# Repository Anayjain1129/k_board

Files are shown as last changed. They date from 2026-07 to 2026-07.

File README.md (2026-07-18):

# K-Board



# Features:

- Rotary Encoder for volume control
- Raspberry Pi Pico
- Customised layout
- QMK firmware
- Awesome Case

# Schematics


# PCB


# Case






# 3d View of all parts together



# BOM
| Name | Quantity | Cost | Link |
|---|---|---|---|
| TTC Silent Red V3 | 84 | $45.11 | [Buy](https://stackskb.com/store/ttc-silent-red-v3-switch/) |
| Durock Smokey Screw-In Stabilizers V2 (4+1 w/ 6.25u spacebar) | 1 | $17.01 | [Buy](https://stackskb.com/store/durock-smokey-screw-in-stabilizers-v2/) |
| EC11 Rotary Encoder with Switch | 1 | $0.00 | Self-sourced |
| Mount Fuji Premium Moa Profile PBT Keycap | 1 | $28.78 | [Buy](https://curiositycaps.in/products/fugaju-premium-moa-profile-pbt-keycap?_pos=21&_sid=c0043ab41&_ss=r) |
| Diode 1N4148 Through-Hole | 100 | $1.06 | [Buy](https://www.amazon.in/dp/B084ZP5BJ3) |
| PCB - (Black Color) | 5 | $40.00 | [Buy](https://jlcpcb.com/) |
| Raspberry Pi Pico | 1 | $6.40 | [Buy](https://www.amazon.in/Raspberry-Pi-Headers-Soldered-Micro/dp/B08WPNM7JB) |
| Heatset and Screws | 1 | $0.00 | Self-sourced |
| Case (top, mid, bot) | 1 | $0.00 | Self-sourced |
| **Total** | | **$138.36** | |

The price may fluctuate due to dollar market trend

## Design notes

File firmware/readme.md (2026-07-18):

# k_board

k_board

*A short description of the keyboard/project*

* Keyboard Maintainer: [Anayjain1129](https://github.com/Anayjain1129)
* Hardware Supported: *The PCBs, controllers supported*
* Hardware Availability: *Links to where you can find this hardware*

Make example for this keyboard (after setting up your build environment):

    make k_board:default

Flashing example for this keyboard:

    make k_board:default:flash

See the [build environment setup](https://docs.qmk.fm/#/getting_started_build_tools) and the [make instructions](https://docs.qmk.fm/#/getting_started_make_guide) for more information. Brand new to QMK? Start with our [Complete Newbs Guide](https://docs.qmk.fm/#/newbs).

## Bootloader

Enter the bootloader in 3 ways:

* **Bootmagic reset**: Hold down the key at (0,0) in the matrix (usually the top left key or Escape) and plug in the keyboard
* **Physical reset button**: Briefly press the button on the back of the PCB - some may have pads you must short instead
* **Keycode in layout**: Press the key mapped to `QK_BOOT` if it is available

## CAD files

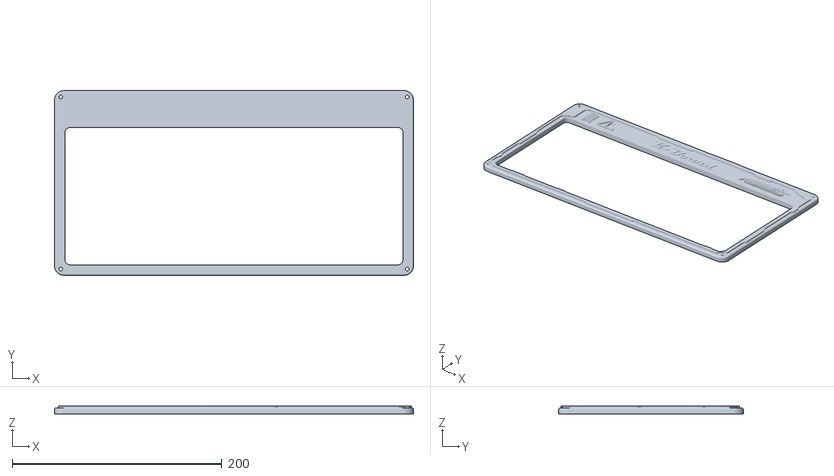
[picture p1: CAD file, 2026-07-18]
cad/top.stl
342.7 x 176.3 x 8.00

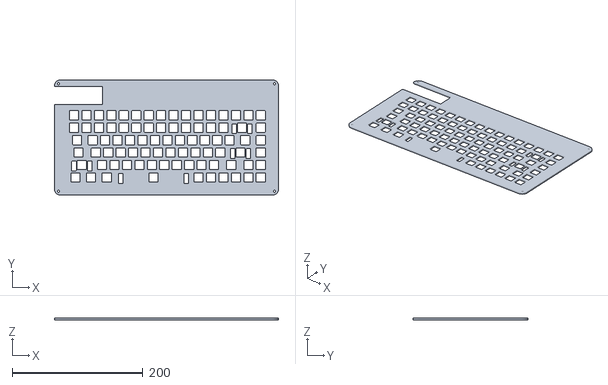
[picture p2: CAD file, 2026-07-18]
production/cad/middle.stl
342.7 x 176.3 x 2.50

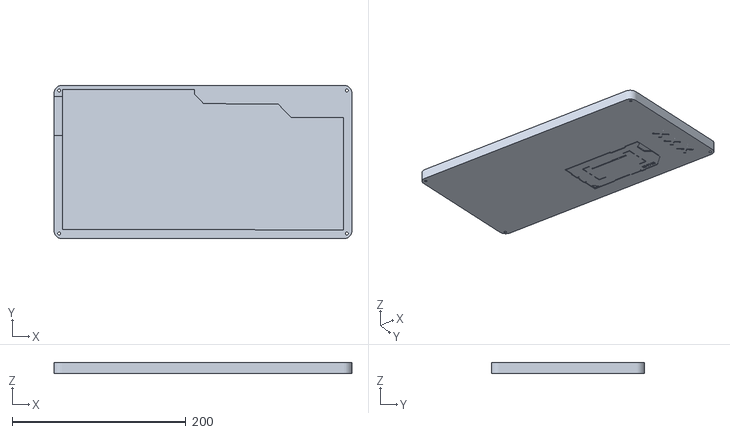
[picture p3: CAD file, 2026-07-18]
cad/bottom.stl
342.7 x 176.3 x 13.0

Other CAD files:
cad/assembly.f3z
cad/bottom.f3d
cad/middle.f3d
cad/top.f3d

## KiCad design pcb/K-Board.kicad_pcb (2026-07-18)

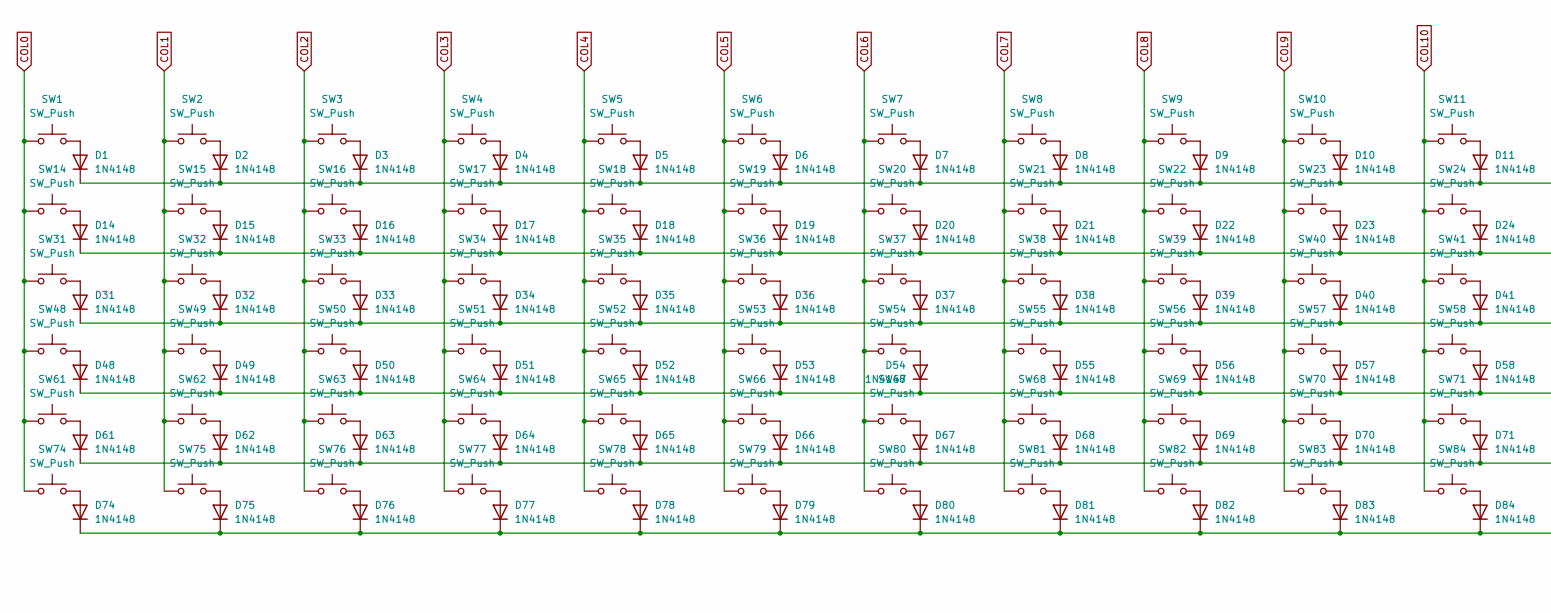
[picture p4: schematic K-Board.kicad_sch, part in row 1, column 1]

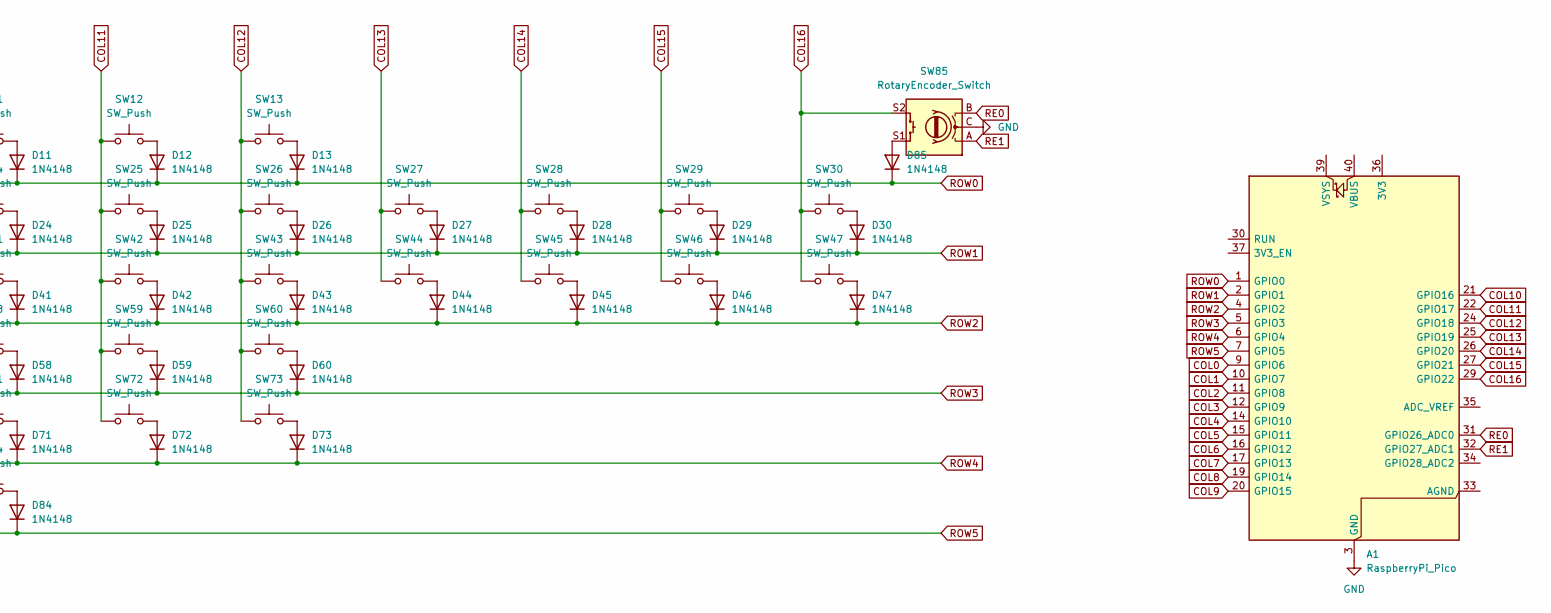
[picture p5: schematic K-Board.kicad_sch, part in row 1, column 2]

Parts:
A1: RaspberryPi_Pico; RaspberryPi_Pico_Common_Unspecified
D1, D2, D3, D4, D5, D6, D7, D8, D9, D10, D11, D12, D13, D14, D15, D16, D17, D18, D19, D20, D21, D22, D23, D24, D25, D26, D27, D28, D29, D30, D31, D32, D33, D34, D35, D36, D37, D38, D39, D40, D41, D42, D43, D44, D45, D46, D47, D48, D49, D50, D51, D52, D53, D54, D55, D56, D57, D58, D59, D60, D61, D62, D63, D64, D65, D66, D67, D68, D69, D70, D71, D72, D73, D74, D75, D76, D77, D78, D79, D80, D81, D82, D83, D84, D85: 1N4148; D_DO-35_SOD27_P7.62mm_Horizontal
SW1, SW2, SW3, SW4, SW5, SW6, SW7, SW8, SW9, SW10, SW11, SW12, SW13, SW14, SW15, SW16, SW17, SW18, SW19, SW20, SW21, SW22, SW23, SW24, SW25, SW26, SW27, SW28, SW29, SW31, SW33, SW34, SW35, SW36, SW37, SW38, SW39, SW40, SW41, SW42, SW43, SW44, SW46, SW48, SW49, SW50, SW51, SW52, SW53, SW54, SW55, SW56, SW57, SW58, SW60, SW62, SW63, SW64, SW65, SW66, SW67, SW68, SW69, SW70, SW71, SW73, SW74, SW79, SW80, SW81, SW82, SW83, SW84: SW_Push; SW_Cherry_MX_1.00u_PCB
SW30: SW_Push; SW_Cherry_MX_2.00u_PCB
SW32, SW45: SW_Push; SW_Cherry_MX_1.50u_PCB
SW47, SW72: SW_Push; SW_Cherry_MX_1.75u_PCB
SW59, SW61: SW_Push; SW_Cherry_MX_2.25u_PCB
SW75, SW76, SW77: SW_Push; SW_Cherry_MX_1.25u_PCB
SW78: SW_Push; SW_Cherry_MX_6.25u_PCB
SW85: RotaryEncoder_Switch; RotaryEncoder_Alps_EC12E-Switch_Vertical_H20mm_CircularMoun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

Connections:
COL0: A1.9 (GPIO6), SW1.1, SW14.1, SW31.1, SW48.1, SW61.1, SW74.1
COL1: A1.10 (GPIO7), SW2.1, SW15.1, SW32.1, SW49.1, SW62.1, SW75.1
COL2: A1.11 (GPIO8), SW3.1, SW16.1, SW33.1, SW50.1, SW63.1, SW76.1
COL3: A1.12 (GPIO9), SW4.1, SW17.1, SW34.1, SW51.1, SW64.1, SW77.1
COL4: A1.14 (GPIO10), SW5.1, SW18.1, SW35.1, SW52.1, SW65.1, SW78.1
COL5: A1.15 (GPIO11), SW6.1, SW19.1, SW36.1, SW53.1, SW66.1, SW79.1
COL6: A1.16 (GPIO12), SW7.1, SW20.1, SW37.1, SW54.1, SW67.1, SW80.1
COL7: A1.17 (GPIO13), SW8.1, SW21.1, SW38.1, SW55.1, SW68.1, SW81.1
COL8: A1.19 (GPIO14), SW9.1, SW22.1, SW39.1, SW56.1, SW69.1, SW82.1
COL9: A1.20 (GPIO15), SW10.1, SW23.1, SW40.1, SW57.1, SW70.1, SW83.1
COL10: A1.21 (GPIO16), SW11.1, SW24.1, SW41.1, SW58.1, SW71.1, SW84.1
COL11: A1.22 (GPIO17), SW12.1, SW25.1, SW42.1, SW59.1, SW72.1
COL12: A1.24 (GPIO18), SW13.1, SW26.1, SW43.1, SW60.1, SW73.1
COL13: A1.25 (GPIO19), SW27.1, SW44.1
COL14: A1.26 (GPIO20), SW28.1, SW45.1
COL15: A1.27 (GPIO21), SW29.1, SW46.1
COL16: A1.29 (GPIO22), SW30.1, SW47.1, SW85.S2
GND: A1.3 (GND), A1.8 (GND), A1.13 (GND), A1.18 (GND), A1.23 (GND), A1.28 (GND), A1.38 (GND), SW85.C
unnamed: D1.2 (A), SW1.2
unnamed: D2.2 (A), SW2.2
unnamed: D3.2 (A), SW3.2
unnamed: D4.2 (A), SW4.2
unnamed: D5.2 (A), SW5.2
unnamed: D6.2 (A), SW6.2
unnamed: D7.2 (A), SW7.2
unnamed: D8.2 (A), SW8.2
unnamed: D9.2 (A), SW9.2
unnamed: D10.2 (A), SW10.2
unnamed: D11.2 (A), SW11.2
unnamed: D12.2 (A), SW12.2
unnamed: D13.2 (A), SW13.2
unnamed: D14.2 (A), SW14.2
unnamed: D15.2 (A), SW15.2
unnamed: D16.2 (A), SW16.2
unnamed: D17.2 (A), SW17.2
unnamed: D18.2 (A), SW18.2
unnamed: D19.2 (A), SW19.2
unnamed: D20.2 (A), SW20.2
unnamed: D21.2 (A), SW21.2
unnamed: D22.2 (A), SW22.2
unnamed: D23.2 (A), SW23.2
unnamed: D24.2 (A), SW24.2
unnamed: D25.2 (A), SW25.2
unnamed: D26.2 (A), SW26.2
unnamed: D27.2 (A), SW27.2
unnamed: D28.2 (A), SW28.2
unnamed: D29.2 (A), SW29.2
unnamed: D30.2 (A), SW30.2
unnamed: D31.2 (A), SW31.2
unnamed: D32.2 (A), SW32.2
unnamed: D33.2 (A), SW33.2
unnamed: D34.2 (A), SW34.2
unnamed: D35.2 (A), SW35.2
unnamed: D36.2 (A), SW36.2
unnamed: D37.2 (A), SW37.2
unnamed: D38.2 (A), SW38.2
unnamed: D39.2 (A), SW39.2
unnamed: D40.2 (A), SW40.2
unnamed: D41.2 (A), SW41.2
unnamed: D42.2 (A), SW42.2
unnamed: D43.2 (A), SW43.2
unnamed: D44.2 (A), SW44.2
unnamed: D45.2 (A), SW45.2
unnamed: D46.2 (A), SW46.2
unnamed: D47.2 (A), SW47.2
unnamed: D48.2 (A), SW48.2
unnamed: D49.2 (A), SW49.2
unnamed: D50.2 (A), SW50.2
unnamed: D51.2 (A), SW51.2
unnamed: D52.2 (A), SW52.2
unnamed: D53.2 (A), SW53.2
unnamed: D54.2 (A), SW54.2
unnamed: D55.2 (A), SW55.2
unnamed: D56.2 (A), SW56.2
unnamed: D57.2 (A), SW57.2
unnamed: D58.2 (A), SW58.2
unnamed: D59.2 (A), SW59.2
unnamed: D60.2 (A), SW60.2
unnamed: D61.2 (A), SW61.2
unnamed: D62.2 (A), SW62.2
unnamed: D63.2 (A), SW63.2
unnamed: D64.2 (A), SW64.2
unnamed: D65.2 (A), SW65.2
unnamed: D66.2 (A), SW66.2
unnamed: D67.2 (A), SW67.2
unnamed: D68.2 (A), SW68.2
unnamed: D69.2 (A), SW69.2
unnamed: D70.2 (A), SW70.2
unnamed: D71.2 (A), SW71.2
unnamed: D72.2 (A), SW72.2
unnamed: D73.2 (A), SW73.2
unnamed: D74.2 (A), SW74.2
unnamed: D75.2 (A), SW75.2
unnamed: D76.2 (A), SW76.2
unnamed: D77.2 (A), SW77.2
unnamed: D78.2 (A), SW78.2
unnamed: D79.2 (A), SW79.2
unnamed: D80.2 (A), SW80.2
unnamed: D81.2 (A), SW81.2
unnamed: D82.2 (A), SW82.2
unnamed: D83.2 (A), SW83.2
unnamed: D84.2 (A), SW84.2
unnamed: D85.2 (A), SW85.S1
RE0: A1.31 (GPIO26_ADC0), SW85.B
RE1: A1.32 (GPIO27_ADC1), SW85.A
ROW0: A1.1 (GPIO0), D1.1 (K), D2.1 (K), D3.1 (K), D4.1 (K), D5.1 (K), D6.1 (K), D7.1 (K), D8.1 (K), D9.1 (K), D10.1 (K), D11.1 (K), D12.1 (K), D13.1 (K), D85.1 (K)
ROW1: A1.2 (GPIO1), D14.1 (K), D15.1 (K), D16.1 (K), D17.1 (K), D18.1 (K), D19.1 (K), D20.1 (K), D21.1 (K), D22.1 (K), D23.1 (K), D24.1 (K), D25.1 (K), D26.1 (K), D27.1 (K), D28.1 (K), D29.1 (K), D30.1 (K)
ROW2: A1.4 (GPIO2), D31.1 (K), D32.1 (K), D33.1 (K), D34.1 (K), D35.1 (K), D36.1 (K), D37.1 (K), D38.1 (K), D39.1 (K), D40.1 (K), D41.1 (K), D42.1 (K), D43.1 (K), D44.1 (K), D45.1 (K), D46.1 (K), D47.1 (K)
ROW3: A1.5 (GPIO3), D48.1 (K), D49.1 (K), D50.1 (K), D51.1 (K), D52.1 (K), D53.1 (K), D54.1 (K), D55.1 (K), D56.1 (K), D57.1 (K), D58.1 (K), D59.1 (K), D60.1 (K)
ROW4: A1.6 (GPIO4), D61.1 (K), D62.1 (K), D63.1 (K), D64.1 (K), D65.1 (K), D66.1 (K), D67.1 (K), D68.1 (K), D69.1 (K), D70.1 (K), D71.1 (K), D72.1 (K), D73.1 (K)
ROW5: A1.7 (GPIO5), D74.1 (K), D75.1 (K), D76.1 (K), D77.1 (K), D78.1 (K), D79.1 (K), D80.1 (K), D81.1 (K), D82.1 (K), D83.1 (K), D84.1 (K)

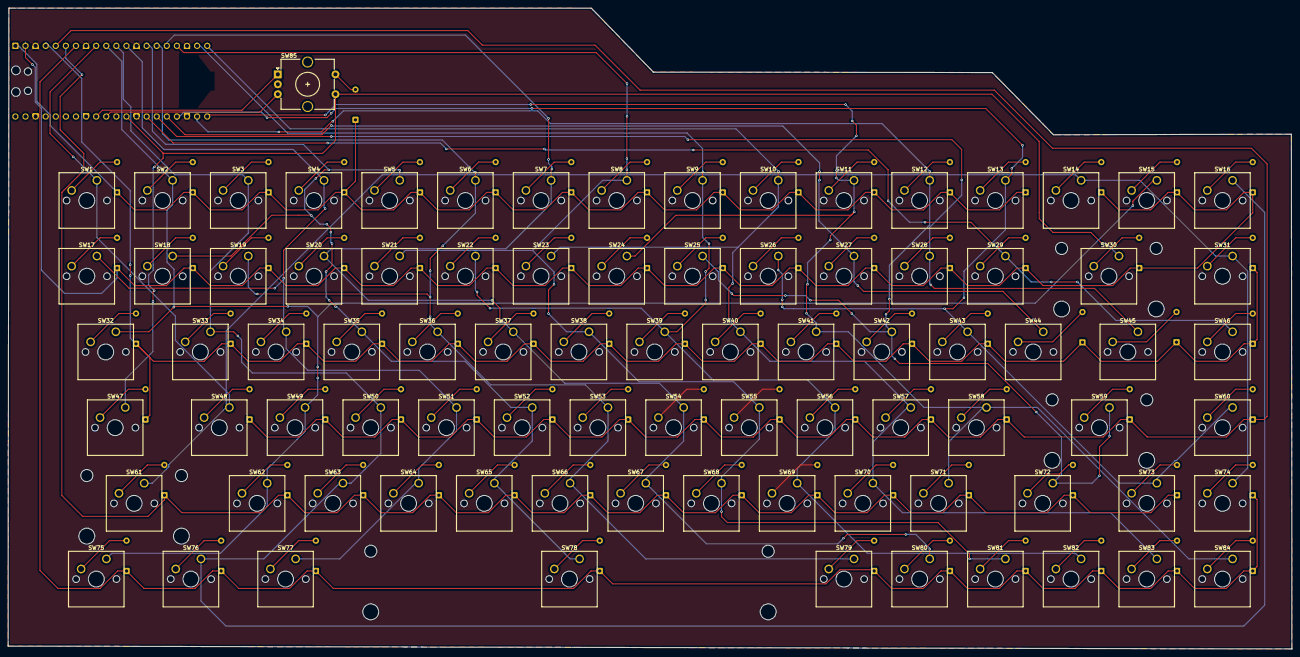
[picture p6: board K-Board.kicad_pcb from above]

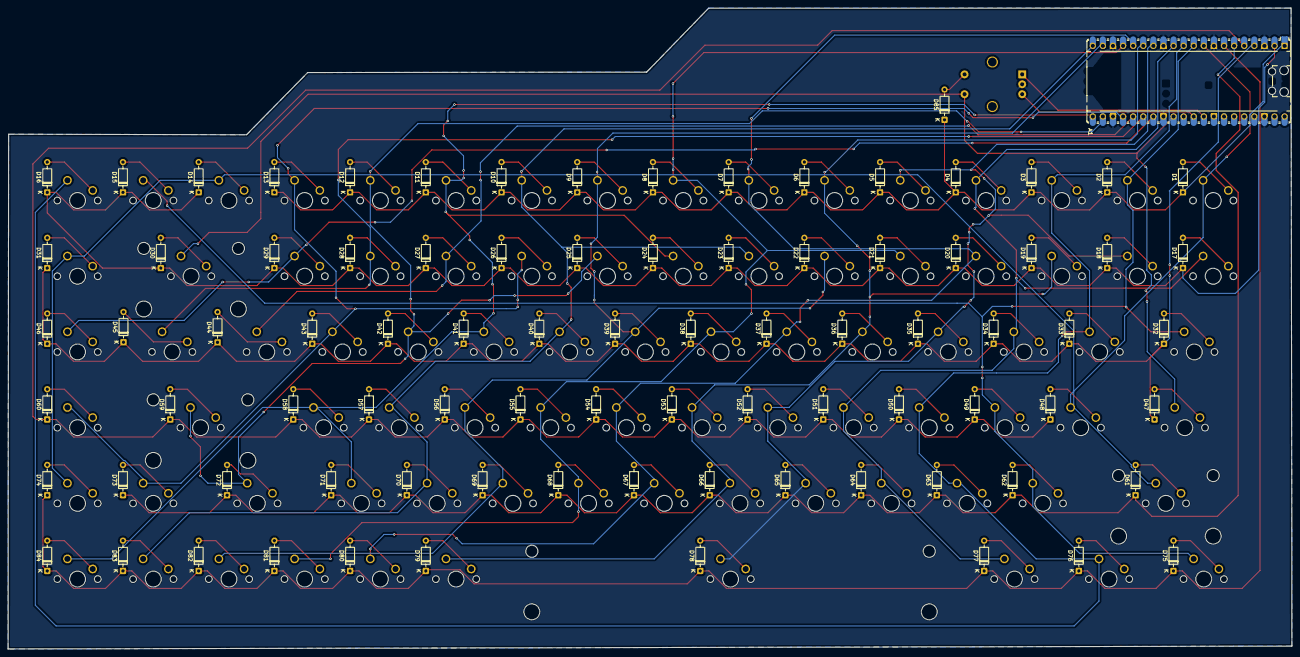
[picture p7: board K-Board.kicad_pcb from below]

Board: 2 copper layers, 323.1 x 161.3 mm, 171 parts (86 on the bottom side), 111 nets.

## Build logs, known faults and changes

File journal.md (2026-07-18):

---
title: K_Board
author: Anay
description: A fully customised keyboard from scratch
created_at: "2026-05-23"
---

# May 3rd: Started with schematics and brainstormed a basic idea! 

I'm using KiCad to make this keyboard Started wtih schematics brainstormed for a basic/rough idea of what layout i have to use! placed the components, wirted a lil bit! read about keyboard mounting styles
lapse link: https://lapse.hackclub.com/timelapse/YrQlb_RHFgfU


**Total time spent: 40min**

# May 7th: completed my schematics!!
first i completed the wiring of my schematics, then i added global labels to wire the switches with my MCU after that i assigned the footprints of my components! after that i tweaked my keyboard layout a bit! then i started with PCB , placed the components! and wired lil bit of diodes! 


**Total time spent: 45min**

# May 8th: working/wiring PCB
just did a lil bit wiring and it's 01:51am am im feeling sleepy so imma just gonna sleep!


**Total time spent: 22min**

# May 9th: wiring PCB
I just did wiring!! and aahhhh it's tuff wiring is tuff i have to use so many via it's still not done yet too! i have so much left that needs to be completed! 


**Total time spent: 1hr 22min**

# May 10th: Completed PCB
Completed all the wiring! In the process i had not actually faced any issues, i tried to have a very unique pcb shape which is to be honest practical and looks very practical! i just had gnd connections left to be connected! so i used fill zone to do that! and via using it my PCB looks pretty cool, i know it looks a bit off not because of no silkscreen but yea! im gonna add it soon, im ending this season here! cause im taking a break for now and uploading a lapse (yes im afraid i'll loose it) so yea! that's it! will take a small break and then start to put the 3d models of the switch so that my pcb looks clean and i get awesome renders lol! (and silkscreen too)


**Total time spent: 1hr**

# May 10th: Switches model assigned & PCB ready for redering 
just assigned 3d models of all the switches in the PCB, there were few places where wiring was not done, so i wierd them too! now the PCB is ready for rendering (looks pretty).


**Total time spent: 38min**

# May 11th: started with case
i faced soo many issuess ahhhh, i didn't knew how to measure the angle/degree in kicad and i spent all this time to learn this, shiii!! but yea i was able to make this! i have made the shape of my keyboard! and i'll make mroe tmr! my brain is cooked. that's it for today! 







**Total time spent: 50min**

# May 12th: Making Case
worked on case, made a a very basic case and i think i have soooo many ideas i can make many thingg on the case i.e. designs!



**Total time spent: 20min**

# May 13th: Made holes for screws! 
made the holes for screws! im using m3 screws. which will be ordered from amazon! just made the holes for screws



**Total time spent: 7min**

# May 16th: Working on case
i just worked on case! the case will have 3 parts in total first bottom, second the middle plate which will hold the switches together, and then the last part top which will make it look cooler lol. i was jus brainstorming and i thought to make cyberpunk themed keyboard, i remember a hackclubber who made cyberpunk themed macropad, and it looked soo awesome so yea im gonna make it in cyberpunk theme too and for now i almost everything is done! now i just have too add more designs i have added a lil bit of designs but i still need to add more so yea! 




**Total time spent: 1hr 36min**

# May 19th: made the top look good
I worked mostly on the top part of the case and ig it looks pretty good now! i think everything looks good except the uh, the side of the case and the bottom of case im still brainstorming what to do on it, but yea im gonna work more on case part tmr! here are the screenshots from today's update- 





**Total time spent: 1hr 38min**

# May 26th: worked on the design of bottom of the case
I was in locking huddle wtih some of my friends, i wokred mostly on graphics part  and also found what all things/ cyberpunk elements to add in the case cause the bottom of the case was soo plane and wa looking plane, so i'm add more designs on the bottom. rest now im gonna work more on this tmr! here are the screenshots.



**Total time spent: 45min**

# July 17/18th: resumed to work on keeb and gonna complete it this time!! 
so i just made some changes in CAD added more designs and then here is the ss of the assembly, then i started to read the QMK docs cause i'll beb using QMK in this keyboard for the firmware and i did faced a lot of issues during this project but yera at the end i just made through! SCIENCE EXAM TMRR RAWRR SLEEPP!!




**Total time spent: 2 hours**

# July 18th: Completed Project!
so i just got back from schl and now i need to lockin like really lockin so yea! i need to do 3.5 hours by 5pm so yea! i just completed everything and setted up github repo and uploaded all the files and stuff! and yea we are done with this project now i just need to submit and make another project!! 

**Total time spent: 36min**

# July 18th: project got rejected! and resubmitted! 
so the project got rejected cause it didn't had BOM now i have added it and now im resubmmitting! 

**Total time spent: 7min**

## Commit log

2026-05-02 1st journal
    Documented the initial brainstorming and schematic design for a custom keyboard project, including a time lapse link and an image.
2026-05-02 Edit journal entry for May 3rd
    Removed brackets and corrected minor typos in the journal entry.
2026-05-07 Update journal with May 7th entry
    Document progress on schematics and PCB design.
2026-05-09 Update journal with May 10th PCB completion entry
    Documented completion of PCB wiring and design details.
2026-05-10 Update journal with PCB and switch model progress
    Added details about 3D models of switches and PCB rendering.
2026-05-11 Update journal with May 11th progress
    Document progress on keyboard case design and time spent learning KiCad.
2026-05-12 Update journal with May 12th entry
    Added new entry for May 12th detailing work on case and ideas.
2026-05-13 Add May 13th journal entry
    Added journal entry for May 13th detailing screw hole creation.
2026-05-19 Document progress on case design for May 19th
    Added a new entry for May 19th detailing progress on the case design and included screenshots.
2026-07-18 Add BOM section with components and links
